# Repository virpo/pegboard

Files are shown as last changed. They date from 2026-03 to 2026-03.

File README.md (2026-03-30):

# 📍 Pegboard

AI-generated 3D-printable pegboard toy from a hand-drawn sketch.

<table>
  <tr>
    <th width="50%">What I gave AI</th>
    <th width="50%">What it gave me</th>
  </tr>
  <tr>
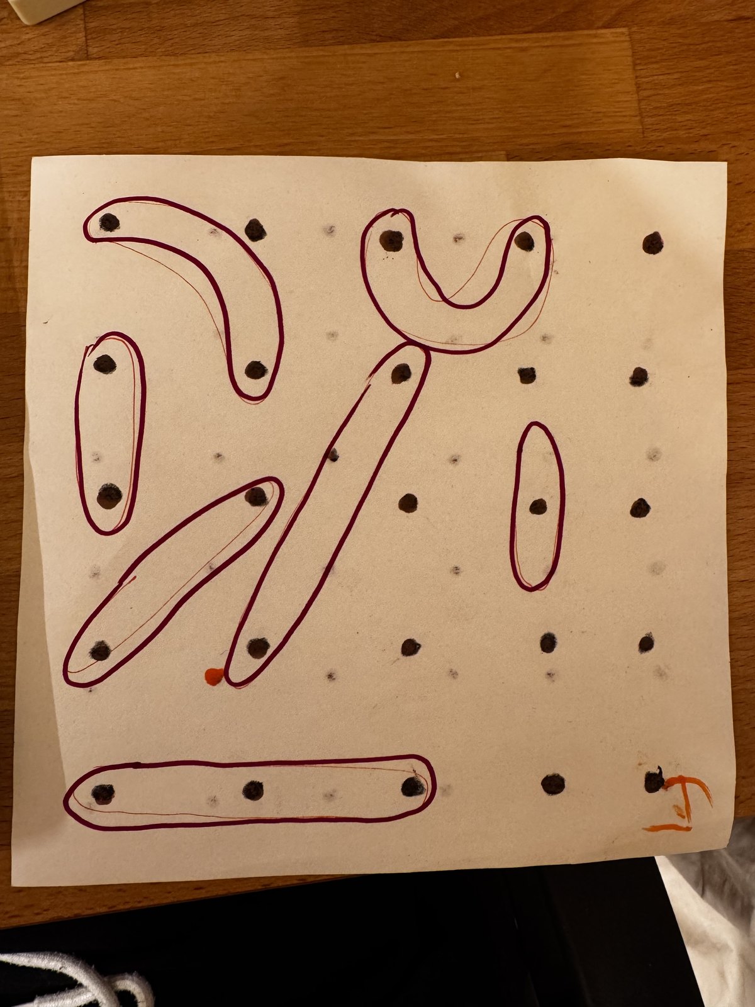
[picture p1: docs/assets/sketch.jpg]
Hand-drawn pegboard sketch
    <td></td>
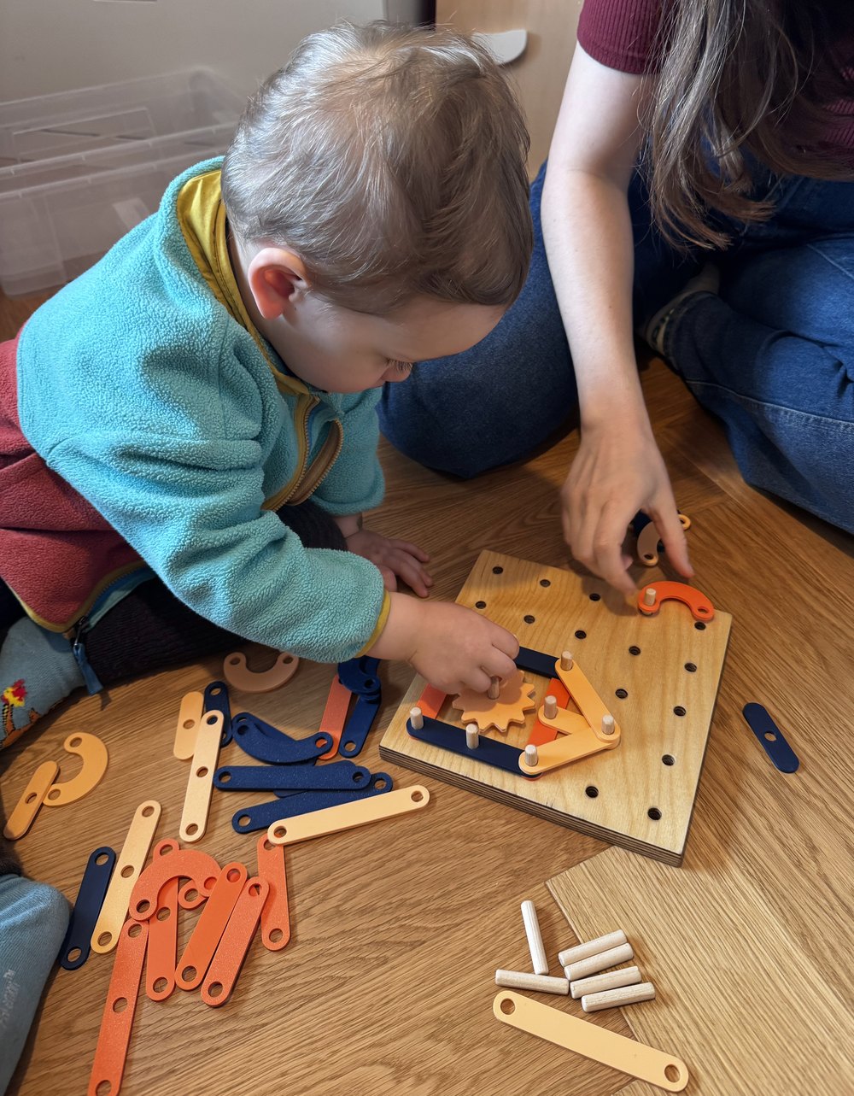
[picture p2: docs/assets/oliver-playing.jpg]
Oli playtesting the first printed pegboard set
    <td></td>
  </tr>
  <tr>
    <td>A rough marker sketch Oli and I drew together. I gave Codex just two dimensions: the holes are `4 cm` apart and the pegs are `8 mm` wide.</td>
    <td>Oli playing with the first printed set, after a little fit-and-feel iteration.</td>
  </tr>
</table>

## Why This Exists

We have pegboards and plywood scraps all over the apartment. I wanted to make a tiny one for Oli, or maybe even hang one on our front door instead of a wreath so visitors would have something to play with.

I had already cut the scrap wood and drilled the first board when I sat down at the computer, ready to lose an hour or two in Fusion 360. Then I looked at the sketch on my desk, took a photo, pasted it into Codex, and added the only dimensions that mattered: the holes are `40 mm` apart and the pegs are `8 mm` wide.

About a minute later I had the first set of pieces. From there I just iterated a little: print, test, adjust, repeat, until the pegs fit snugly, the pieces felt good by hand, and the gears turned smoothly.

Everything in this repo stays as small Python generators instead of hand-edited meshes, which made those tweaks easy. The time I did not spend drawing every variant in CAD turned into time I could spend printing, testing, and playing with Oli instead.

The current set is a `40 mm` system with seven play pieces, one tuned peg, four gears, and two printable boards.

## Use AI To Tweak It

This repo is intentionally easy to modify with coding agents. [AGENTS.md](AGENTS.md) has the current dimensions, folder layout, and the few rules needed to extend the set safely.

You can ask an agent to:

- build a bigger pegboard like `6x6`
- make the pegs longer or shorter
- add new pieces for different peg combinations
- scale the whole system up or down
- generate tighter or looser fit-test variants

## What's in this repository

<p align="center">
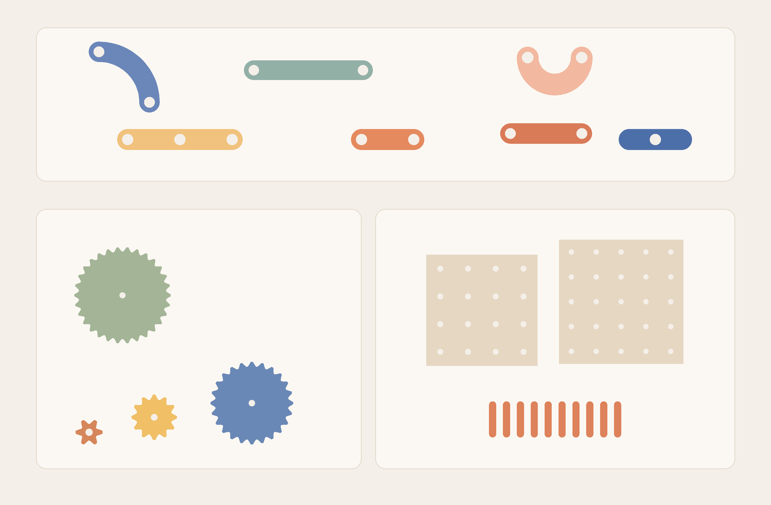
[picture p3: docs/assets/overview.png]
Overview render showing the play pieces, gears, printable pegboards, and tuned pegs included in the repository
  
</p>

| Play pieces | Gears | Pegboards and pegs |
| --- | --- | --- |
| Seven flat pieces in [models/pieces/](models/pieces) with `8.45 mm` holes, tuned to lift on and off the pegs easily. | Four smooth gears in [models/gears/](models/gears), tuned to mesh on the `40 mm` peg grid. | Two printable boards in [models/boards/](models/boards) plus the tuned peg in [models/pieces/](models/pieces). |

## Repository layout

- `models/`  
  Final STL exports plus the board-fit prototypes.
- `scripts/`  
  Parametric generators for pieces, gears, boards, and README assets.
- `docs/`  
  Supporting notes plus the README images.
- `AGENTS.md`  
  Instructions for coding agents that want to extend the set.

## Tuned dimensions

- Grid pitch: `40.0 mm`
- Piece hole diameter: `8.45 mm`
- Gear hole diameter: `8.45 mm`
- Peg: `7.72 mm` diameter, `40.0 mm` long, `1.2 mm` end roundover
- Printed board hole diameter: currently `8.30 mm`, still being validated

## Regenerate

```bash
python3 -m venv .venv
. .venv/bin/activate
pip install -r requirements.txt
python scripts/generate_pegboard_shapes.py
python scripts/generate_pegboard_gears.py
python scripts/generate_pegboard_board.py
python scripts/generate_repository_assets.py
```

## Notes

- [docs/pieces.md](docs/pieces.md)
- [docs/gears.md](docs/gears.md)
- [docs/boards.md](docs/boards.md)
- [models/board_prototypes/README.md](models/board_prototypes/README.md)

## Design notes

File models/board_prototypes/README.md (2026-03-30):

# Board Fit Prototypes

Generated from `generate_pegboard_board.py`.

These are minimal single-hole coupons to calibrate the peg fit for a fully 3D printed backboard before committing to a full board print.

## Best guess

- Peg CAD diameter: `7.72 mm`
- Observed printed peg diameter: about `7.92 mm`
- Coupon thickness: `15.0 mm`
- Coupon wall thickness: `4.0 mm`
- Recommended first test: `8.30 mm`
- Prototype hole diameters: `8.25 mm, 8.30 mm, 8.35 mm`

The board should hold the peg more tightly than the loose-moving play pieces, so this test range is centered lower than the piece-hole test range.
The coupon thickness is set to the same `15 mm` as the intended printed board so the test matches the final board more closely.

Once you pick the winning hole diameter, the same script can generate full printed boards at `15.0 mm` thickness and `40.0 mm` peg spacing.

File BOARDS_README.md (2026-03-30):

# Printable Pegboards

Generated from `generate_pegboard_board.py`.

These are the current full-board exports using the present best-guess printed-board hole diameter.
The board-hole size is still provisional until the single-hole coupon test is confirmed physically.

## Current provisional settings

- Hole diameter: `8.30 mm`
- Board thickness: `15.0 mm`
- Grid pitch: `40.0 mm`
- Edge margin: `20.0 mm`

## Files

- `boards/01_pegboard_4x4_hole_8p30_provisional.stl`
- `boards/02_pegboard_5x5_hole_8p30_provisional.stl`
- The `4x4` board is `160 x 160 mm` overall.
- The `5x5` board is `200 x 200 mm` overall.

If the coupon test later points to a different hole diameter, update `BOARD_HOLE_DIAMETER_MM` in `generate_pegboard_board.py` and regenerate.

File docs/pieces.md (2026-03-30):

# Pegboard Shapes

Generated from `generate_pegboard_shapes.py`.

## Default dimensions

- Pegboard pitch: `40.0 mm`
- Piece width: `16.0 mm`
- Piece thickness: `3.0 mm`
- Peg hole diameter: `8.45 mm`
- Recommended peg diameter: `7.72 mm`
- Peg length: `40.0 mm`
- Peg end roundover: `1.2 mm`

The hole diameter is intentionally tuned upward because your printer closes printed holes relative to CAD. The recommended peg diameter is tuned downward because your printer makes outside diameters print slightly oversized. If your printer runs tighter or looser later, edit `HOLE_DIAMETER_MM` and `PEG_DIAMETER_MM` in `scripts/generate_pegboard_shapes.py` and re-run the script.

The single exported peg is the measured best-fit version: `7.72 mm` CAD diameter, `40.0 mm` length, and `1.2 mm` end roundover.

## Files

Each STL in `models/pieces/` is a separate printable part. `models/pieces/all_shapes_layout.stl` contains the seven flat pieces arranged on one virtual plate for quick viewing. The tuned peg is exported into the same folder as its own STL.

Drag any STL directly into Bambu Studio. If you want to inspect or re-export later, keep the Python source file because all dimensions are parametric there.

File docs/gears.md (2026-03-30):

# Pegboard Gears

Generated from `generate_pegboard_gears.py`.

## Key dimensions

- Grid pitch: `40.0 mm`
- Gear hole diameter: `8.45 mm`
- Gear thickness: `6.0 mm`
- Module locked to board: `4.444444 mm`
- Tooth counts: `6, 12, 24, 30`

## What changed from the original

This variant keeps the same board-locked tooth counts and overall look, but it
reduces backlash and smooths tooth entry in two ways:

- Tooth thickness at pitch circle increased to `0.405 * tooth pitch`
- Tooth tip width increased to `0.185 * tooth pitch`
- Root relief kept at `0.08 * tooth pitch` to preserve valley clearance
- Each flank uses a gentle convex quadratic curve with `0.2 mm` bulge
- A small in-plane roundover of `0.4 mm` softens the 2D tooth outline
- A real 3D edge break of `0.4 mm` is applied to the top and bottom outer edges
- Thickness increased to `6.0 mm` to reduce tilt on the peg while turning

## Intended mesh pairs

- `6T` + `12T`: `40.0 mm` center distance, use peg-step vectors `[[1, 0], [0, 1]]`
- `6T` + `30T`: `80.0 mm` center distance, use peg-step vectors `[[2, 0], [0, 2]]`
- `12T` + `24T`: `80.0 mm` center distance, use peg-step vectors `[[2, 0], [0, 2]]`
- `24T` + `30T`: `120.0 mm` center distance, use peg-step vectors `[[3, 0], [0, 3]]`

## Sampled Non-Overlap Check

- `6T` + `12T`: max sampled overlap `0.0 mm^2`, min sampled gap `0.2017 mm`, phase offset `15.0°`
- `12T` + `24T`: max sampled overlap `0.0 mm^2`, min sampled gap `0.3021 mm`, phase offset `7.5°`
- `24T` + `30T`: max sampled overlap `0.0 mm^2`, min sampled gap `0.3537 mm`, phase offset `6.0°`
- `6T` + `30T`: max sampled overlap `0.0 mm^2`, min sampled gap `0.2333 mm`, phase offset `6.0°`

## Pegs to remove around each gear

Offsets are relative to the gear center hole on the grid. These are conservative keep-clear zones based on the gear outer radius plus peg radius.

- `6T`: `[]`
- `12T`: `[]`
- `24T`: `[[-1, -1], [-1, 0], [-1, 1], [0, -1], [0, 1], [1, -1], [1, 0], [1, 1]]`
- `30T`: `[[-1, -1], [-1, 0], [-1, 1], [0, -1], [0, 1], [1, -1], [1, 0], [1, 1]]`

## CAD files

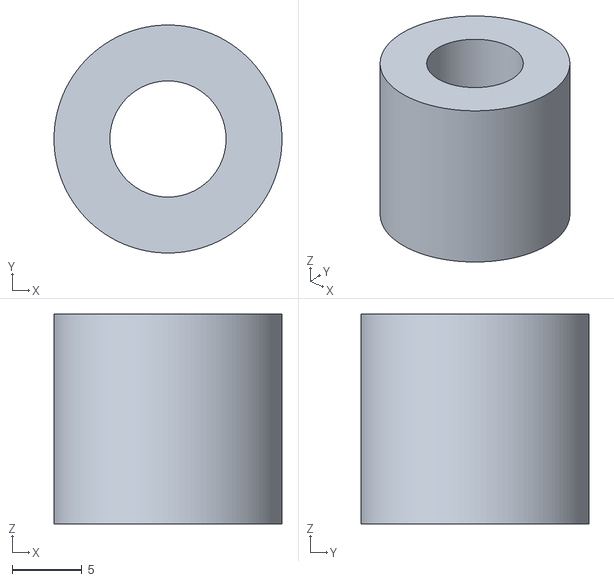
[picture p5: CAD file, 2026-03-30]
models/board_prototypes/02_board_fit_coupon_hole_8p30_thick_15_recommended.stl
16.3 x 16.3 x 15.0

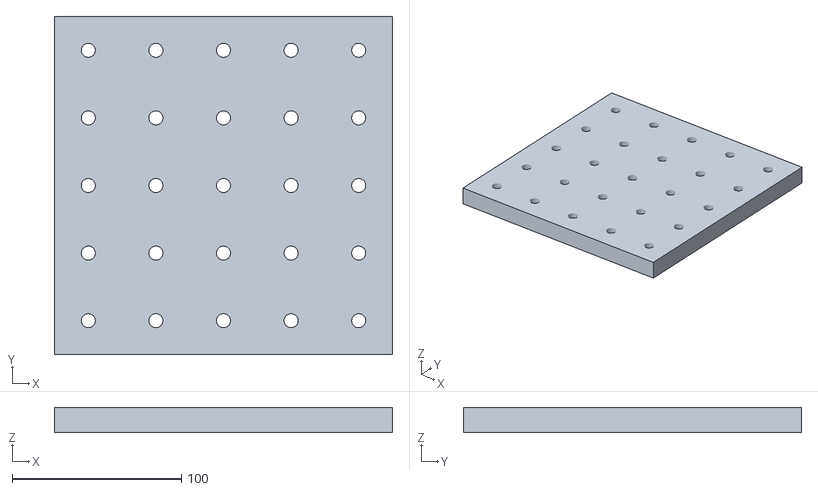
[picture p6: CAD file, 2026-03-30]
models/boards/02_pegboard_5x5_hole_8p30_provisional.stl
200.0 x 200.0 x 15.0

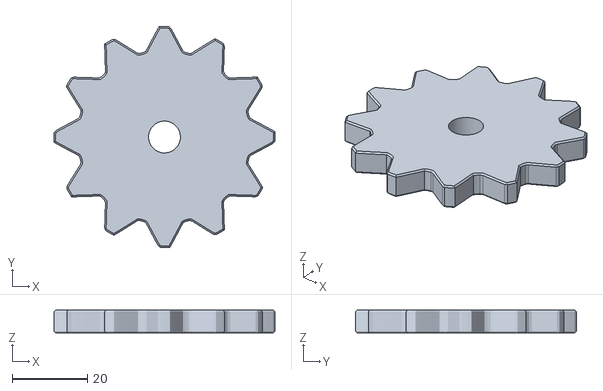
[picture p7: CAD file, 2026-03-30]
models/gears/02_gear_12t.stl
58.7 x 58.7 x 6.00

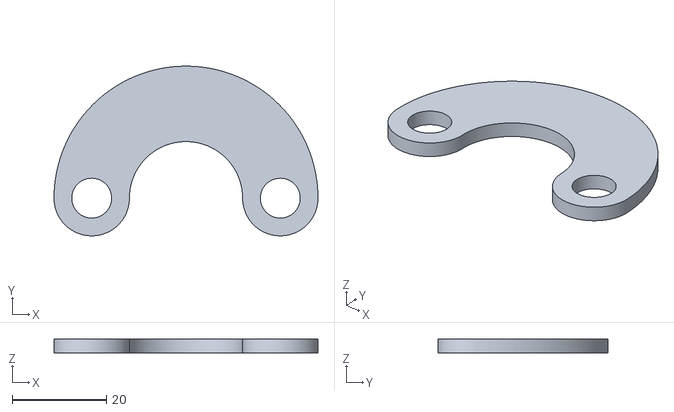
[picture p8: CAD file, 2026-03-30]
models/pieces/06_half_circle_2_holes.stl
56.0 x 36.0 x 3.00

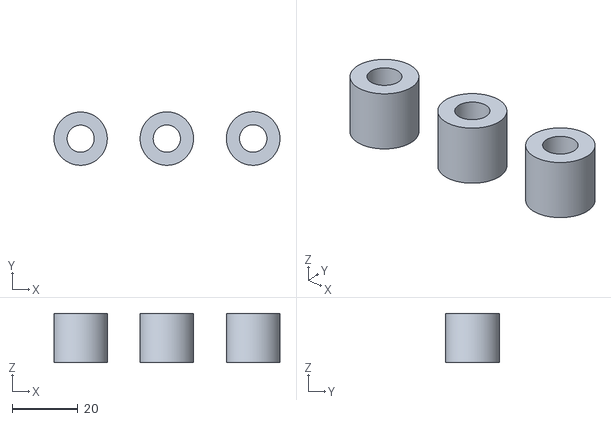
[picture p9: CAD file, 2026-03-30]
models/board_prototypes/all_board_fit_coupons_layout.stl
68.9 x 16.4 x 15.0

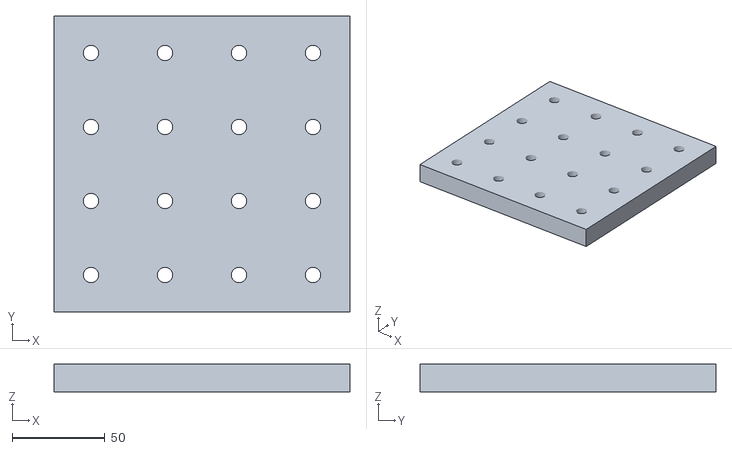
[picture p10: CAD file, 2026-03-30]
models/boards/01_pegboard_4x4_hole_8p30_provisional.stl
160.0 x 160.0 x 15.0

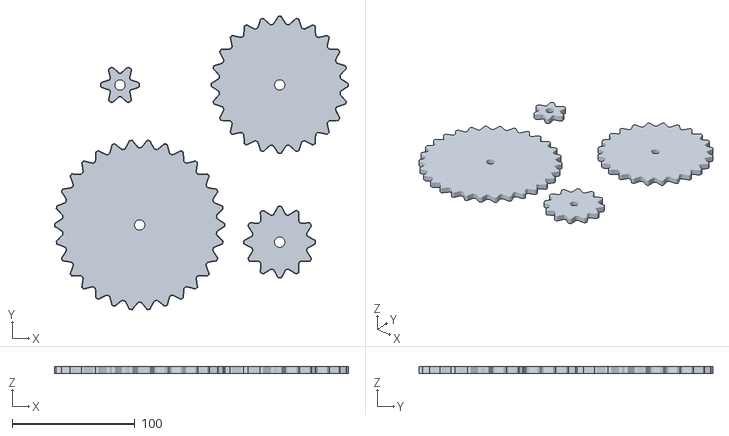
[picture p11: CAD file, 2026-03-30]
models/gears/all_gears_layout.stl
239.3 x 239.1 x 6.00

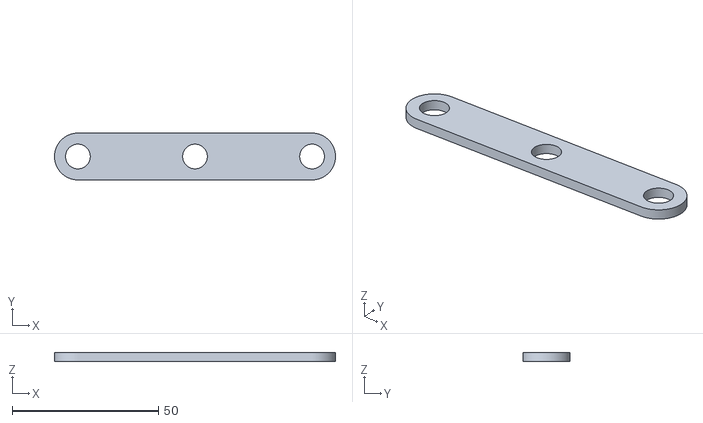
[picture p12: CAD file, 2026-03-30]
models/pieces/02_straight_3_holes.stl
96.0 x 16.0 x 3.00

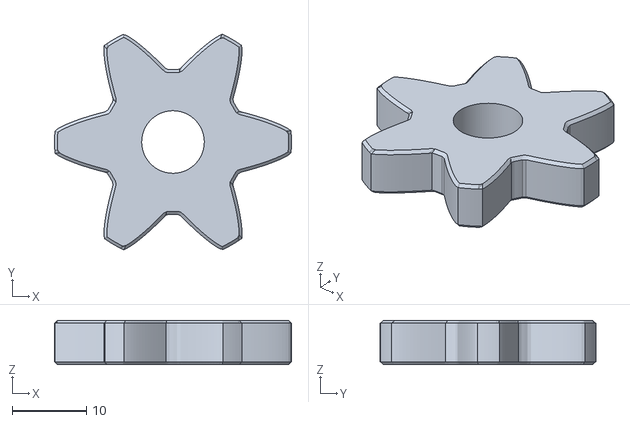
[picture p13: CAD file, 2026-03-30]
models/gears/01_gear_6t.stl
32.0 x 29.1 x 6.00

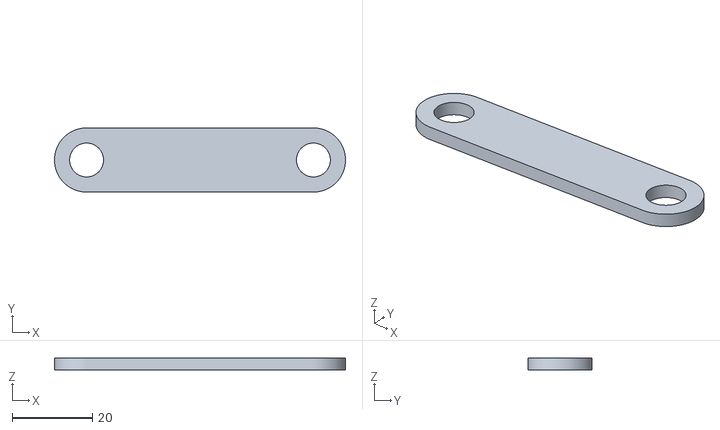
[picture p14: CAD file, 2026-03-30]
models/pieces/04_diagonal_2_holes.stl
72.6 x 16.0 x 3.00

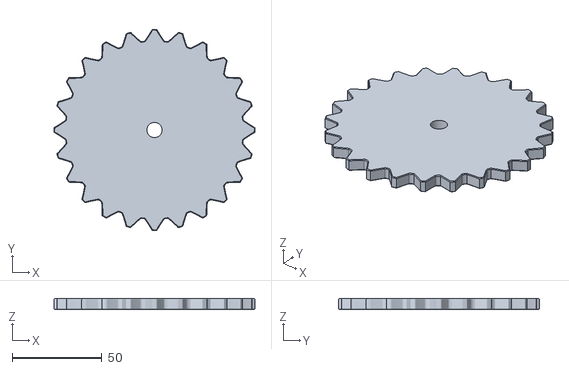
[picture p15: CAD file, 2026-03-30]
models/gears/03_gear_24t.stl
112.0 x 112.0 x 6.00

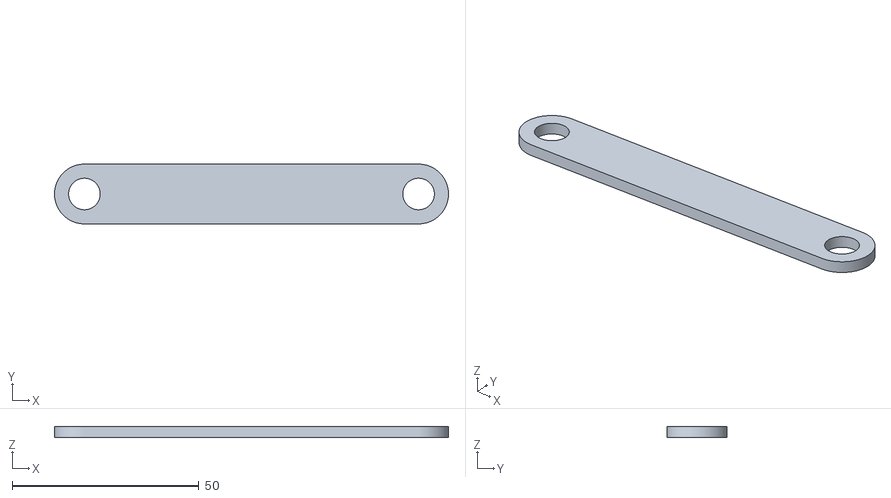
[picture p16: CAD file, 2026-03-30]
models/pieces/05_offset_diagonal_2_holes.stl
105.4 x 16.0 x 3.00

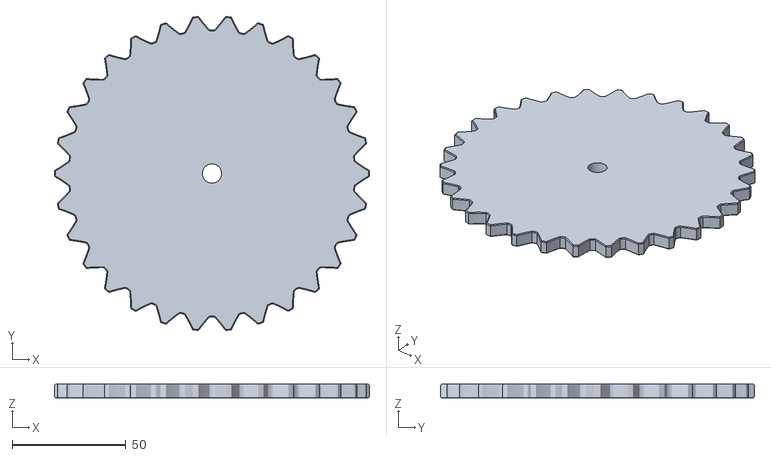
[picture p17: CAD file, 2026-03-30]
models/gears/04_gear_30t.stl
138.7 x 138.2 x 6.00

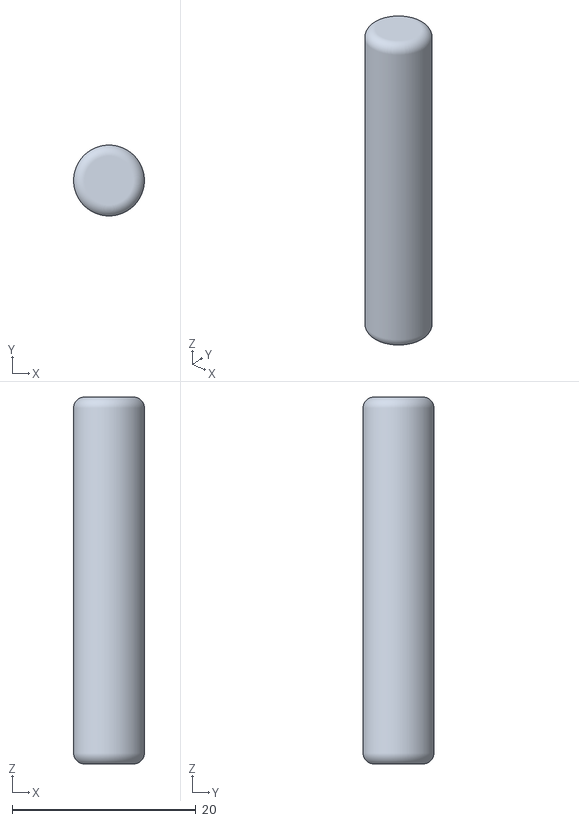
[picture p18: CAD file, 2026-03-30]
models/pieces/08_peg_7p72x40_roundover_1p2_recommended.stl
7.72 x 7.72 x 40.0

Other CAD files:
models/board_prototypes/01_board_fit_coupon_hole_8p25_thick_15.stl
models/board_prototypes/03_board_fit_coupon_hole_8p35_thick_15.stl
models/pieces/01_straight_2_holes.stl
models/pieces/all_shapes_layout.stl
models/pieces/03_rotor_single_hole.stl
models/pieces/07_quarter_circle_2_holes.stl

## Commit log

2026-03-30 Initial pegboard play set
    [01_board_fit_coupon_hole_8p25_thick_15.stl, 01_gear_6t.stl, 01_pegboard_4x4_hole_8p30_provisional.stl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]
2026-03-30 Tighten README story
2026-03-30 Refine board and peg spacing in overview
2026-03-30 Reorganize repo layout
    [01_board_fit_coupon_hole_8p25_thick_15.stl, 01_gear_6t.stl, 01_pegboard_4x4_hole_8p30_provisional.stl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]
